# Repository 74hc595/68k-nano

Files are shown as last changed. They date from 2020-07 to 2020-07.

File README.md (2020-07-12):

# 68k nano

A minimal single-board computer based on the venerable ["Texas Cockroach"](https://youtu.be/UaHtGf4aRLs?t=2074)
Motorola 68000 16/32-bit microprocessor.

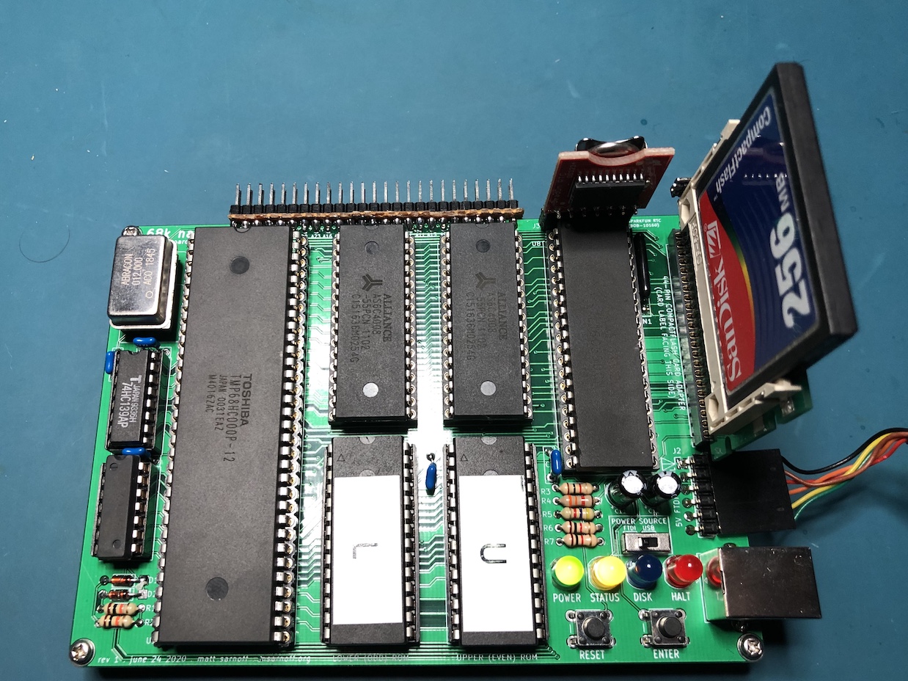
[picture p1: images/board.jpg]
Board image


## Features

- 68HC000 processor running at 12MHz
- 1MB RAM
- 64KB ROM
- 16550 UART providing a 5V FTDI serial port
- 44-pin IDE connector for CompactFlash card adapter
- Connector for SparkFun DS3234 real-time clock
- Only two 74HC glue logic chips required

This might be capable of running uClinux, but I haven't tried it!

## Hardware

The 68k nano hardware is simple and straightforward. It can be built on a
breadboard (though there may be stability issues at higher clock speeds).

### Memory map

Due to the minimal address decoding circuitry, accessing certain memory regions
will cause multiple devices to be selected. This should be avoided.

```
$000000-0xFFFF     ROM (repeats 16 times)
$100000-1FFFFF  X  Forbidden (multiple devices selected)
$200000-2FFFFF     ROM (mirror of $000000-0FFFFF)
$300000-$7FFFF  X  Forbidden (multiple devices selected)
$800000-8FFFFF     Open bus (available for expansion)
$900000-9xxxxF     CompactFlash card
$A00000-AxxxxF     UART
$B00000-BFFFFF  X  Forbidden (multiple devices selected)
$C00000-CFFFFF     RAM
$D00000-DFFFFF  X  Forbidden (multiple devices selected)
$E00000-EFFFFF     RAM (mirror of $C00000-CFFFFF)
$F00000-FFFFFF  X  Forbidden (multiple devices selected)
```

This is summarized with the following equations:

```
/ROMSEL  = /A23
/RAMSEL  =  A22
/UARTSEL =  A23 * /A22 * A21
/CARDSEL =  A20
```

### I/O

The 16550's modem control lines are used as a bit-banged SPI interface. A 7-pin
header is provided for [SparkFun's "DeadOn" DS3234 real-time clock board](https://www.sparkfun.com/products/10160).
Access to SPI is therefore achieved via the 16550's Modem Control Register and Line
Status Register.

A 2mm pitch 44-pin IDE connector is provided for storage devices. This is
intended for CompactFlash card adapters (operating in 16-bit True IDE mode) but
may also work with parallel ATA hard disks. (not tested)

### Interrupts

All interrupt sources are routed through the 16550. All 16550 interrupts invoke
the level 1 autovector (vector offset `$064`) and it is up to the software to
determine the source of the interrupt.

### Building it

`bom.txt` contains a bill of materials. As of this writing (July 2020), all
components are available from major distributors like [Mouser](https://mouser.com)
and [Jameco](https://jameco.com). If purchasing 68000s from eBay, note that [vintage
ICs are a common target of counterfeiters](https://medium.com/supplyframe-hardware/the-underground-parts-store-identifying-counterfeit-computer-chips-3020adbb01f7).
For this project I used [Toshiba TMP68HC000P-12 chips from Jameco](https://www.jameco.com/shop/ProductDisplay?catalogId=10001&langId=-1&storeId=10001&productId=2288039) and
they work just fine.

All parts are through-hole for that extra vintage feel. Note that some of the
decoupling capacitors (C4, C5, C6, C8, and C10) are underneath ICs, so open-frame
IC sockets are required. Large IC sockets can also be expensive (_especially_
DIP-64 sockets!) so a cheaper alternative is to use [breakaway SIP 0.1" machine-pin
headers](https://www.amazon.com/dp/B0187LTEX2/ref=cm_sw_em_r_mt_dp_U_M5IbFbVJ3NVDH).

Due to the spacing of the chips, Textool ZIF sockets won't fit. For the ROMs
U5 and U7, [Aries 28-526-10 low-profile ZIF sockets](https://www.jameco.com/shop/ProductDisplay?catalogId=10001&langId=-1&storeId=10001&productId=102745) will fit,
but _barely_. The release latch may scrape against the RAM IC to its north,
but I've found that it's not a huge deal.

You can use either a full-can or half-can oscillator for X1. Note that if using
an oscillator with a frequency other than 12 MHz, you'll have to update the `F_CPU`
value in the Makefile. (see below) Also note that, if using a 68HC000, the minimum
clock frequency is 4 MHz.

The 44-pin IDE header accepts a CompactFlash adapter board such as [this one](https://www.amazon.com/gp/product/B07Y2MTS13), available from Amazon and other vendors.

## Software

This project uses the [vasm](http://sun.hasenbraten.de/vasm/) assembler and a
standard Makefile. Python 3 and [PySerial](https://pythonhosted.org/pyserial/)
are also required to upload programs to the computer via the serial port. The
Makefile also contains rules for burning ROM images to AT28C256 EEPROMs using
[minipro](https://gitlab.com/DavidGriffith/minipro/) if you have a [TL866II+](https://www.jameco.com/shop/ProductDisplay?catalogId=10001&langId=-1&storeId=10001&productId=2297823)
programmer. (If you don't have a chip programmer, you should get a TL866II+, they
are reasonably priced and available from a number of vendors.)

### Building it

Running `make rom` will build the ROM image and split it into "odd" and "even"
halves, `rom-l.bin` and `rom-u.bin`. Each file should be 32,768 bytes exactly.
Running `make burnrom` will write these files to a pair of AT28C256 EEPROMs
using minipro.

**Note:** if using an oscillator with a frequency other than 12 MHz, change the
value of `F_CPU` appropriately in the Makefile.

The `BAUD` variable in the Makefile sets the baud rate of the serial interface.
Use the included script `baudrate.py` to determine which baud rates are usable
with a given oscillator frequency.

### ROM features

The ROM is fairly minimal--it's closer to a bootloader than an operating system.
It supports loading programs from the root directory of a FAT16-formatted
CompactFlash card and some basic debugging functionality. It also provides a
small set of system calls for I/O to simplify application programs.

The power-up process is as follows:
- Initialize serial port to 57600 baud, 8 data bits, no parity, 1 stop bit.
- Test RAM. If a RAM failure occurs, the failed address is written to the serial
port and the Status LED flashes rapidly. (This is prone to failure when running
on a breadboard at higher clock speeds.)
- Check for the real-time clock module. If found, print the current date and
time to the serial port.
- Check for a CompactFlash card, and attempt to mount the first partition if it
is FAT16-formatted.
- If the "ENTER" pushbutton is NOT held down:
  - If a valid card is inserted, check for a file in the root directory named
    `STARTUP.BIN`. If found, load it into RAM and execute it.
  - If `STARTUP.BIN` was not loaded, enter an interactive command shell.
- If the "ENTER" pushbutton is held down, enter the interactive command shell
  and bypass execution of `STARTUP.BIN`.

Example startup sequence (without `STARTUP.BIN`):
```
68K NANO - ROM VERSION 00009900 (20200708)
(C) 2020 MATT SARNOFF (MSARNOFF.ORG)
TESTING RAM...PASSED

RAM: 1,048,576 BYTES
ROM: 65,536 BYTES
CPU: 12,000,000 HZ
TIME IS 2020-07-07 19:14:36
CARD DETECTED: 250,608 KB 'NO NAME    '
CANNOT LOAD STARTUP.BIN - FILE NOT FOUND

TYPE ? [ENTER] FOR HELP.
>
```

### Command shell

If `STARTUP.BIN` was not loaded, an interactive command shell is available via
the serial port. (57600 baud, 8 data bits, no parity, 1 stop bit). Type `?` and
press Enter for a list of supported commands. They are summarized briefly here.
Note that commands and filenames are _case-insensitive_.

- `.L` - list files in the root directory of the CompactFlash card. Long filenames
  and hidden files are not displayed.
- `.I` - print low-level information about the filesystem on the CompactFlash card.
- `.P file` - print the contents of the file named `file` in the root directory
  of the CompactFlash card as ASCII text.
- `.H file` - print the contenxt of the file named `file` in the root directory
  of the CompactFlash card as a hexdump.
- `.T` - print the current date and time as reported by the real-time clock module.
- `.T YYYYMMDDWWhhmmss` - set the current date and time. The new date/time should
  be expressed as a string of 16 decimal digits with no separators. `WW` should
  be a 2-digit weekday between `01` and `07` inclusive. You can obtain the
  current date/time in this format with the Unix command `date "+%Y%m%d0%u%H%M%S"`.
- `.D` - enter the debugger.
- `file` - any other command is interpreted as a filename to be loaded from the
  root directory of the CompactFlash card and executed. Unlike MS-DOS, the file
  extension _is_ required. e.g. to execute the file named _foo.bin_, enter `FOO.BIN`.
  (`FOO` will attempt to load a file named _foo_ with no extension).

### Serial loader

A break condition on the serial input line enters the serial loader, allowing
programs to be uploaded to RAM from a host computer. The Python script `serload.py`
and the Makefile rules `make load` and `make run` take care of this.

### Debugging

A hardware exception causes a transfer into a basic debugger. The Status LED
flashes rapidly and a register dump is printed to the serial port:

```
*ILLEGAL INSTRUCTION
D0=00000064  D1=0000000A  D2=00000038  D3=00000009
D4=00000000  D5=00000000  D6=00000000  D7=00000000
A0=00E0003C  A1=00001D40  A2=00000000  A3=00F00000
A4=00000000  A5=00000000  A6=000001E2  A7=00EFFFFA
SR=-S0--Z--  PC=00001D3A              USP=7F7EFFDF

[A]BORT/[C]ONTINUE/[S]TEP?
```

Supported commands are:
- `a` - abort execution and return to system.
- `c` - (attempt to) continue execution. (the Trace bit is cleared)
- `s` - set the Trace bit and single-step.

`TRAP #15` is treated as a breakpoint instruction that also enters the debugger.

### API

See `API.md` for a detailed description of the system calls provided by the ROM
API and guidelines for application programs.

## Known issues and shortcomings

- ROM is always present at the bottom of the address space, so the exception
  vectors cannot be overridden by application code.
- Interrupt handling is a hack, since all interrupt sources go through the 16550.
- Address decoding leaves little room for expansion.
- System calls should set the condition codes to simplify application code.

## Future directions

This is a small-scale project. I'm thinking about desiging a larger 68000 board
in the future, so I probably won't continue working on this one. Here are some
project ideas that I won't have time to tackle, but you're welcome to:

- Running an existing 68k monitor like [TUTOR](http://www.easy68k.com/paulrsm/mecb/mecb.htm)
  or [zBug](http://www.kswichit.com/68k/68k.html).
- Running a language like [EhBASIC](https://github.com/jefftranter/68000/tree/master/ehbasic) or a Forth.
- Adding FAT16 write support.
- Booting [uClinux](https://www.bigmessowires.com/2014/11/17/68-katy-68000-linux-on-a-solderless-breadboard/) like Steve Chamberlin did with [68 Katy](https://www.bigmessowires.com/category/68katy/).
- Using the DS3234 real-time clock's SQW output to generate a periodic interrupt.
  (likely necessary for uClinux)

## About

Open hardware, released under the terms of the 3-clause BSD license.

Copyright 2020 Matt Sarnoff.

http://twitter.com/txsector

http://msarnoff.org

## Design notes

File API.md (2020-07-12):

## Application programming

Programs are loaded into RAM starting at the address `APPMEMSTART` (currently
defined as `$E00100`, 256 bytes past the start of RAM). Execution also begins at
this location.

Application programs are executed in supervisor mode. The stack pointer `A7` is
initialized to the end of RAM (`$00F00000`) and registers `D0-D7/A0-A6` are
initialized to `$00000000`.

The interrupt priority level is set to `0`, i.e. interrupts are enabled at
program start.

The UART is enabled and set to 57600 baud, 8 data bits, no parity, 1 stop bit.
The line status interrupt is enabled. A break condition on the serial input
terminates execution of the application and enters the serial loader (see above).

The `TRAP #n` instruction is used to perform system calls. (see below)

### System calls

Application programs can use basic input/output routines in the ROM using the
`TRAP` instruction. (This limits the number of syscalls to 16. Future ROM revisions
may use [A-traps](https://en.wikipedia.org/wiki/Macintosh_Toolbox).)

#### Calling convention

- `D0-D1` - integer arguments.
- `A0-A1` - pointer arguments.
- Additional arguments passed on the stack.
- `D0-D1` - integer return values.
- `A0-A1` - pointer return values.
- `D2-D7/A2-A7/SR` - preserved.
- Registers `D0-D1/A0-A1` not used for return values may have undefined contents
  upon return to the caller. (i.e. the callee may use them as scratch registers)
- The caller is responsible for removing arguments passed on the stack.

The `sys` macro can be used as a wrapper around the `TRAP` instruction.

A common convention for some system calls is to return 0 in `D0` on success, or
a nonzero error code in `D0` on failure. Note that since system calls preserve
condition codes, an explicit `tst d0` is required before branching to an error
handler.

#### `TRAP #0` - `Exit` - return to system

- **Arguments:**
  - none
- **Returns:**
  - none
- **Function:**
  - Terminates the application and returns to the system. This will relaunch
    `STARTUP.BIN` (if present on card) or return to the command shell.

#### `TRAP #1` - `WaitBtn` - wait for button to be pressed

- **Arguments:**
  - none
- **Returns:**
  - none
- **Function:**
  - Pauses execution until the "ENTER" pushbutton on the board is pressed and
    released.

#### `TRAP #2` - `OutChar` - write one character to output device

- **Arguments:**
  - `D0.B` - character to write
- **Returns:**
  - `D0.B` - unmodified
- **Function:**
  - Write one character to the current output device. (The default output device
    is the serial port; see "Input/output customization" below for more info.)
- **Example:**
```
; write a newline character to the output device
        moveq   #$0a,d0
        sys     OutChar
```

#### `TRAP #3` - `OutStr` - write null-terminated string to output device
- **Arguments:**
  - `A0.L` - pointer to null-terminated string
- **Returns:**
  - none
- **Function:**
  - Write a null-terminated string to the current output device.
- **Example:**
```
; write "hello world!" to the output device, followed by a newline
        lea.l   hello,a0
        sys     OutStr
hello:  dc.b    "hello world!\n",0
```

#### `TRAP #4` - `OutFmt` - write formatted string to output device
- **Arguments:**
  - `A0.L` - pointer to null-terminated format string
  - format arguments on stack (caller is responsible for cleanup)
- **Returns:**
  - none
- **Function:**
  - Write a formatted string to the current output device. Format arguments are
    taken from the stack, with the most-recently-pushed quantity treated as the
    first format argument.
  - Unlike C's `printf`, format specifiers are single bytes in the range `$E0-$FF`.
    See `syscalls.inc` for the full list.
  - Since the 68000 stack must always stay word-aligned, byte quantities must
    be pushed on the stack as words.
- **Example:**
```
; writes "567 xyz 89ABCDEF" to the output device, followed by a newline
        move.l  #2309737967,-(sp) ; second argument, printed as 32-bit hex
        move.w  #$237,-(sp)       ; first argument, printed as 16-bit decimal
        lea.l   fmtstr,a0
        sys     OutFmt
        addq    #6,sp
fmtstr: dc.b    FMT_U16," xyz ",FMT_H32,"\n",0
```

#### `TRAP #5` - `InChar` - read one character from input device
- **Arguments:**
  - none
- **Returns:**
  - `D0.B` - received character
- **Function:**
  - Waits for a character to become available from the current input device and
    returns it. (The default input device is the serial port; see "Input/Output
    handlers" below for more info.)
- **Example:**
```
; wait for a character to be typed, then print its hex value surrounded by brackets
        sys     InChar
        move.w  d0,-(sp)
        lea.l   fmtstr,a0
        sys     OutFmt
        addq    #2,sp
fmtstr: dc.b    "[",FMT_H8,"]",0
```

#### `TRAP #6` - `PromptStr` - prompt for string from input device
- **Arguments:**
  - `A0.L` - pointer to destination buffer
  - `D0.L` - maximum allowed length of string
  - `D1.W` - delimiter character and option flags
    - **bits 0-7:** delimiter (terminate prompt when this character is received)
    - **bit 8:** if set, received characters are _not_ echoed to the output device
    - **bit 9:** if set, control characters like Backspace and Ctrl-C are _not_ interpreted
- **Returns:**
  - `A0.L` - unmodified (points to start of string)
  - `(A0)` - user-supplied string with a terminated null byte
  - `D0.L` - number of characters received (excluding null byte)
- **Function:**
  - Prompts for a string from the input device. Returns when the delimiter character
    specified by `D1.B` is received, or (if bit 9 of `D1` is clear) when Ctrl-C (`$03`)
    is received.
  - The string is null-terminated. The buffer pointed to by `A0` should have sufficient
    space for `D0`+1 bytes.
  - If bit 9 of `D1` is clear, the following control characters are interpreted:
    - **Ctrl-C** (`$03`): return immediately with an empty string
    - **Ctrl-H** (`$08`, **DEL** (`$7F`): delete most-recently-entered character
      from the input buffer and (if bit 8 of `D1` is clear) output a backspace
      escape sequence
    - **Ctrl-M** (`CR`, `$0D`): translated to Ctrl-J (`LF`, `$0A`)
- **Example:**
```
; ask for the user's name
        lea.l   name,a0
        moveq   #32,d0    ; max length is 32 bytes (one less than buffer size)
        moveq   #$0a,d1   ; stop when a newline character is received
        sys     PromptStr
; print it
        move.l  a0,-(sp)
        lea.l   fmtstr,a0
        sys     OutFmt
        addq    #4,sp
fmtstr: dc.b    "Hello, ",FMT_S,"!\n",0
name:   dcb.b   33
```

#### `TRAP #7` - `ReadSector` - read one 512-byte sector from the CompactFlash card
- **Arguments:**
  - `D0.L` - sector number (LBA)
  - `D1.L` - number of bytes to read (pass any value >= 512 to load entire sector)
  - `A0.L` - address of destination buffer (must be word-aligned)
- **Returns:**
  - `D0.B` - error code, or 0 if successful
  - `D1.L` - decremented by the number of bytes read
  - `A0.L` - points one byte past the last byte written to the destination buffer
- **Function:**
  - Reads the numbered sector from the CompactFlash card into RAM. An error code
    is returned in `D0` if an error occurs (e.g. no card inserted or invalid sector number)
  - To facilitate reading of multiple sectors into the same buffer, `A0` is advanced
    to point one byte past the last byte written, and `D1` is decremented by the
    actual number of bytes read.
- **Example:**
```
; read the master boot record
        moveq   #0,d0     ; read sector number 0
        moveq   #-1,d1    ; read whole sector
        lea.l   buf,a0
        sys     ReadSector
; print it as a hexdump
        move.l  #512,-(sp) ; number of bytes to dump
        pea     buf        ; start of buffer
        lea.l   fmtstr,a0
        sys     OutFmt
        addq    #8,sp
fmtstr: dc.b    FMT_HEXDUMP,"\n",0
buf:    dcb.b   512
```

#### `TRAP #8` - `ListDirectory` - traverse the root directory of the CompactFlash card
- **Arguments:**
  - `A0.L` - pointer to buffer of at least `DIRBUFSIZE` bytes (must be word-aligned)
  - `D0.L` - should be nonzero on first call; zero on subsequent calls
- **Returns:**
  - `A0.L` - preserved
  - `A1.L` - pointer to 32-byte directory entry within the buffer
  - `D0.W` - status
    - if `D0.W = 0`, there are still entries to iterate over
    - if `D0.W < 0`, iteration is complete
    - if `D0.W > 0`, an error occurred (error code in lower 8 bits)
- **Function:**
  - Iterates over the entries in the root directory of the CompactFlash card.
  - On the first call, the user should pass a nonzero value in `D0`, and should
    set `D0` to zero on subsequent calls.
  - `A0` should be a pointer to a temporary buffer. This can be in a fixed location
    or on the stack. Its contents should not be modified by application code during
    directory traversal.
  - After each call, `A1` points to a 32-byte [FAT16 directory entry](https://en.wikipedia.org/wiki/Design_of_the_FAT_file_system#Directory_entry).
  - Hidden files, deleted files, volume labels, and empty entries are skipped over.
- **Example:**
```
; set up buffer on stack
        link    a6,#-DIRBUFSIZE
        move.l  sp,a0
        moveq   #-1,d0  ; d0 should be nonzero on first call
; loop over entries
.loop:  sys     ListDirectory
        tst.w   d0
        bmi     .done
        bne     .error
        ; do something with the directory entry here
        moveq   #0,d0   ; d0 should be zero on subsequent calls
        bra     .loop
.done:  ; all done
.error: ; handle error
        unlk    a6      ; deallocate temporary buffer
```

#### `TRAP #9` - `FindFile` - look up the named file in the root directory of the CompactFlash card
- **Arguments:**
  - `A0.L` - pointer null-terminated 8.3 filename
  - `A1.L` - pointer to 32-byte buffer where the directory entry will be copied to
- **Returns:**
  - `D0.B` - status code (0 on success, nonzero on error)
  - `A1.L` - preserved
- **Function:**
  - Traverse the root directory until a file with the given name is found.
    Its directory entry is then copied into the 32-byte buffer pointed to by `A1`.
  - The filename should be specified as a DOS-style 8.3 filename (e.g. `FOO.TXT`)
    and is case-insensitive. Long filenames are not considered.
  - Hidden files are ignored. (this is a probably a bug)
- **Example:**
```
; print the size of the file named TEST.TXT
        lea.l   fname,a0
        lea.l   buf,a1
        sys     FindFile
        move.l  FSIZE(a1),-(sp) ; get file size from directory entry
        lea.l   fmtstr,a0
        sys     OutFmt          ; print file size
        addq    #4,sp
fname:  dc.b    "TEST.TXT",0
fmtstr: dc.b    "FILE SIZE: ",FMT_U32," BYTES",0
buf:    dcb.b   32
```

#### `TRAP #10` - `ReadFile` - read the contents of the named file in the root directory of the CompactFlash card into memory
- **Arguments:**
  - `A0.L` - pointer null-terminated 8.3 filename (case-insensitive)
  - `A1.L` - address where the file should be loaded into
  - `D0.L` - maximum number of bytes to load (passing -1 loads entire file)
- **Returns:**
  - `D0.B` - status code (0 on success, nonzero on error)
  - `A0.L` - pointer to beginning of destination memory buffer (orig. value of `A1`)
  - `A1.L` - actual number of bytes loaded
- **Function:**
  - Loads the full contents of the named file into memory.
  - The filename should be specified as a DOS-style 8.3 filename (e.g. `FOO.TXT`)
    and is case-insensitive. Long filenames are not considered.
  - Hidden files are ignored. (this is a probably a bug)
  - Does not return an error if the file is larger than the maximum number of
    bytes specified in `D0`. (this would be a nice enhancement to make it easier
    to detect cases where a file is too big)
- **Example:**
```
; print the first 32K of a file named TEST.TXT
        lea.l   fname,a0
        lea.l   buf,a1
        move.l  #32768,d0
        sys     ReadFile
        move.l  d1,-(sp)  ; number of bytes read
        move.l  a0,-(sp)  ; start of buffer
        lea.l   fmtstr,a0
        sys     OutFmt
        addq    #8,sp
fname:  dc.b    "TEST.TXT",0
fmtstr: dc.b    FMT_BUF,"\n",0
buf:    dcb.b   32768
```

#### `TRAP #11` - `GetDateTime` - read current date and time from the real-time clock
- **Arguments:**
  - none
- **Returns:**
  - `D0.L` - date
    - **bits 31-16:** year (four BCD digits)
    - **bits 15-8:** month (two BCD digits)
    - **bits 7-0:** date (two BCD digits)
  - `D1.L` - weekday and time
    - **bits 26-24:** weekday (one BCD digit)
    - **bits 23-16:** hour (two BCD digits)
    - **bits 15-8:** minute (two BCD digits)
    - **bits 7-0:** second (two BCD digits)
- **Function:**
  - If no real-time clock is present, `D0` and `D1` will both equal 0.
  - If the time is not set (e.g. there has been a power failure), bit 31 of `D0`
    will be set.
- **Example:**
```
; print the date and time
        sys     GetDateTime
        tst.l   d0
        bmi     .time_not_set
        beq     .no_rtc
        lea.l   fmtstr,a0
        movem.l d0-d1,-(sp)
        sys     OutFmt
        addq    #8,sp
fmtstr: dc.b    "DATE IS ",FMT_DATE," AND TIME IS ",FMT_TIME,"\n",0
```

#### `TRAP #12` - `SetDateTime` - set date and time
- **Arguments:**
  - none
- **Returns:**
  - `D0.L` - date
    - **bits 31-16:** year (four BCD digits)
    - **bits 15-8:** month (two BCD digits)
    - **bits 7-0:** date (two BCD digits)
  - `D1.L` - weekday and time
    - **bits 26-24:** weekday (one BCD digit)
    - **bits 23-16:** hour (two BCD digits)
    - **bits 15-8:** minute (two BCD digits)
    - **bits 7-0:** second (two BCD digits)
- **Function:**
  - No validation of the date (bounds-checking fields, ensuring valid BCD) is performed.
- **Example:**
```
; set date and time to Monday, July 6, 2020, 12:34:56
        move.l  #$01123456,d0 ; msb of 01 = Monday
        move.l  #$20200706,d1
        sys     SetDateTime
```

#### `TRAP #13` - `GetSysInfo` - get pointer to system information structure
- **Arguments:**
  - none
- **Returns:**
  - `A0.L` - pointer to system information structure in ROM
    - `0(A0).L` - CPU clock speed in Hz
    - `4(A0).L` - RAM size in bytes
    - `8(A0).L` - ROM size in bytes
    - `12(A0).L` - ROM date
    - `16(A0).W` - ROM major revision
    - `18(A0).W` - ROM minor revision
- **Function:**
  - Allows application code to retrieve system information.

#### `TRAP #14` - reserved

#### `TRAP #15` - `Breakpoint` - enter the debugger
- **Arguments:**
  - none
- **Returns:**
  - none
- **Function:**
  - Prints a register dump and enters the debugger. 

#### Input/output customization

The longword-sized RAM locations `OUTCH_VEC` and `INCH_VEC` contain addressed of
routines used for character output and input. These can be customized to allow
input and output to be redirected.

At boot, the vectors are initialized to routines that write to and read from
the serial port.

`OUTCH_VEC` should contain the address of a function that accepts the byte to
be written in `D0`. It should preserve `A2-A7/D2-D7`.

`INCH_VEC` should contain the address of a function that waits for a byte to
become available and then returns it in `D0`. it should preserve `A2-A7/D2-D7`.

Formatted output using the `OutFmt` system call can also be customized:
- `HEXDIGITS` contains the address of a 16-character string containing the
  character set to use when printing hexadecimal numbers
- `DATE_SEP` contains the byte used as a separator character between components
  when the `FMT_DATE` specifier is used. At boot, it defaults to hyphen `-`.
- `TIME_SEP` contains the byte used as a separator character between components
  when the `FMT_TIME` specifier is used. At boot, it defaults to colon `:`.
- `THOUSANDS_SEP` contains the byte used as a thousands grouping separator when
  printing signed and unsigned decimal values. At boot, it defaults to comma `,`.
  To suppress thousands separators, set it to ASCII NUL. (zero byte)

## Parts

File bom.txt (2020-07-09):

Ref     Part                                            Distributor SKU
----------------------------------------------------------------------------------------------------------
C1-C10  0.1uF decoupling capacitor (ceramic/monolithic)
C11,C12 10uF electrolytic capacitor, 16V+
D1-D2   1N5817 Schottky diode (1N4148 also works)
D3-D6   5mm LED (your choice of color)
J1      USB-B PCB-mount right-angle connector           Jameco 2096245
J2      6-position 0.1" male right-angle header
J3      (optional) 7-position 0.1" header
J4      2x22 2mm header
JP1     3-position 0.1" male straight header + jumper
R1,R2   10k resistor, 1/4W
R3      1k resistor, 1/4W
R4-R7   Resistors for LEDs D3-D6 (330/1k)
RN1     10k bussed resistor network (SIP-7)
SW1,SW2 6mm tactile switch
U1      74HC139 dual 2-to-4 line decoder (DIP-16)
U2      74HC14 hex inverting Schmitt trigger (DIP-14)
U3      68000 microprocessor (DIP-64)                   Jameco 2288039
U4,U6   AS6C4008-55PCN 512Kx8 static RAM (DIP-32)       Jameco 242448           Mouser 913-AS6C4008-55PCN
U5,U7   AT28C256 32Kx8 EEPROM (DIP-28)                  Jameco 74843            Mouser 556-AT28C25615PU
U8      TL16C550 UART (DIP-40)                          Jameco 288809
X1      5V oscillator (DIP-8 or DIP-14)

Optional peripherals
--------------------
Low profile ZIF-28 sockets for U5/U7 - Jameco 102745 (Aries 28-526-10)
SparkFun DeadOn RTC Breakout - https://www.sparkfun.com/products/10160
CompactFlash to 2.5" 44-pin IDE adapter - https://www.amazon.com/gp/product/B07Y2MTS13

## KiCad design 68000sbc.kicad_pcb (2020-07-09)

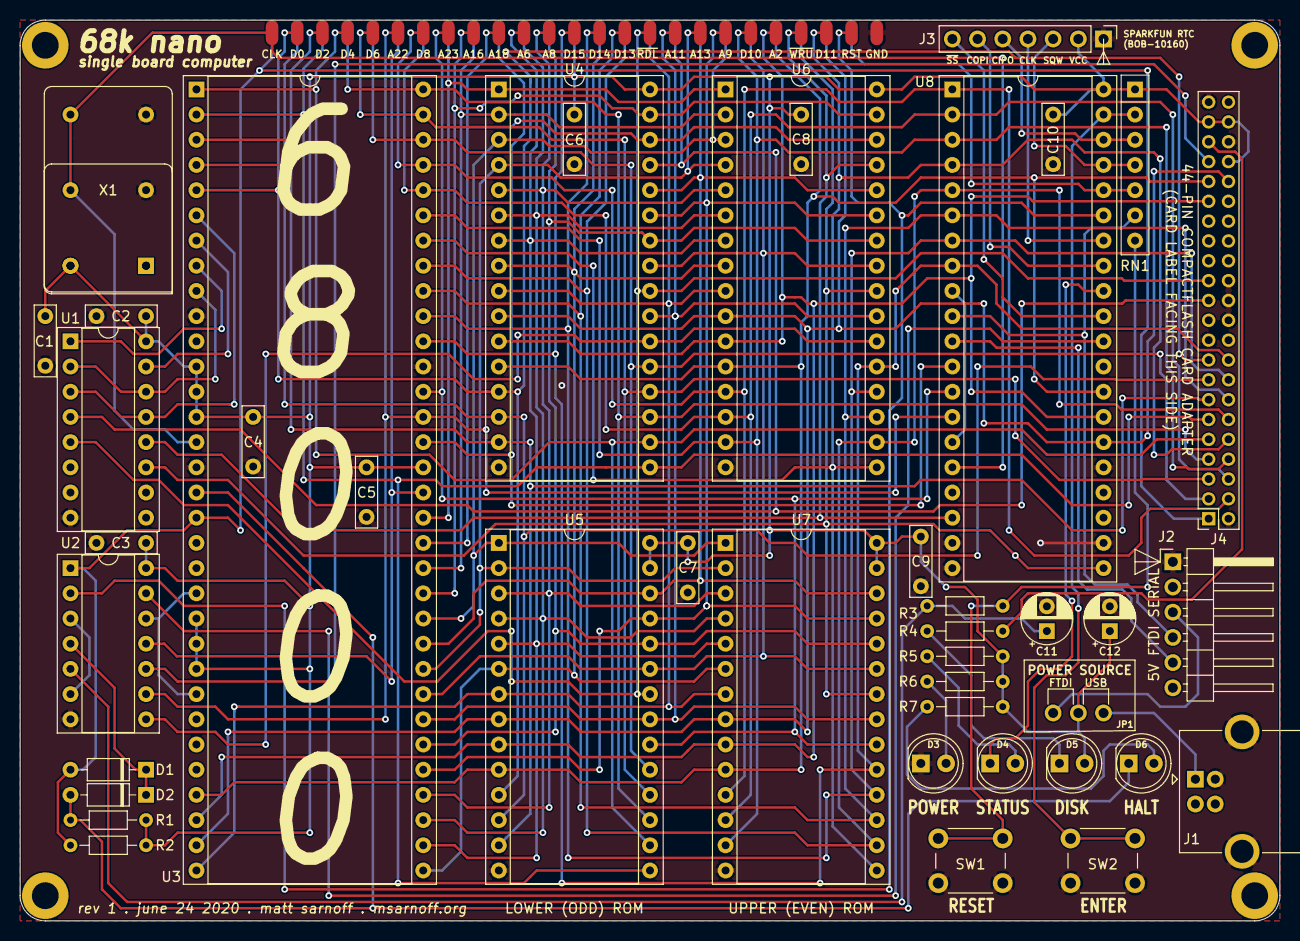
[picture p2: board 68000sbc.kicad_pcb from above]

Board: 2 copper layers, 127.0 x 90.8 mm, 45 parts (1 on the bottom side), 80 nets.

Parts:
C1, C2, C3, C4, C5, C6, C7, C8, C9, C10: 0.1uF; C_Rect_L7.0mm_W2.0mm_P5.00mm
C11, C12: 10uF; CP_Radial_D5.0mm_P2.50mm
D1, D2: 1N5817; D_DO-35_SOD27_P7.62mm_Horizontal
D3: POWER; LED_D5.0mm
D4: LED; LED_D5.0mm
D5: CARD; LED_D5.0mm
D6: HALT; LED_D5.0mm
J1: USB_B; USB_B_OST_USB-B1HSxx_Horizontal
J2: 5V FTDI SERIAL; PinHeader_1x06_P2.54mm_Horizontal
J3: RTC (SparkFun BOB-10160); PinHeader_1x07_P2.54mm_Vertical
J4: CFCARD/IDE; PinHeader_2x22_P2.00mm_Vertical
J5: EXPANSION (F.Cu); PadRow_1x25_P2.54mm
J6: EXPANSION (B.Cu); PadRow_1x25_P2.54mm
JP1: POWER SELECT; PinHeader_1x03_P2.54mm_Vertical
R1, R2: 10k; R_Axial_DIN0204_L3.6mm_D1.6mm_P7.62mm_Horizontal
R3: 1k; R_Axial_DIN0204_L3.6mm_D1.6mm_P7.62mm_Horizontal
R4, R5, R6, R7: 1k*; R_Axial_DIN0204_L3.6mm_D1.6mm_P7.62mm_Horizontal
RN1: 10k; R_Array_SIP7
SW1: RESET; SW_PUSH_6mm
SW2: BTN1; SW_PUSH_6mm
U1: 74HC139; DIP-16_W7.62mm_Socket
U2: 74HC14; DIP-14_W7.62mm_Socket
U3: TMP68HC000P-12; DIP-64_W22.86mm_Socket
U4, U6: AS6C4008-55PCN; DIP-32_W15.24mm_Socket
U5, U7: 28C256; DIP-28_W15.24mm_Socket
U8: TL16C550; DIP-40_W15.24mm_Socket
X1: 12MHz; Oscillator_DIP-14
X2: 12MHz; Oscillator_DIP-8

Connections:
/A1: J4.35, J6.21, U3.29, U4.12, U5.10, U6.12, U7.10, U8.28
/A2: J4.33, J5.21, U3.30, U4.11, U5.9, U6.11, U7.9, U8.27
/A3: J4.36, J6.23, U3.31, U4.10, U5.8, U6.10, U7.8, U8.26
/A4: J6.16, U3.32, U4.9, U5.7, U6.9, U7.7
/A5: J6.14, U3.33, U4.8, U5.6, U6.8, U7.6
/A6: J5.11, U3.34, U4.7, U5.5, U6.7, U7.5
/A7: J6.11, U3.35, U4.6, U5.4, U6.6, U7.4
/A8: J5.12, U3.36, U4.5, U5.3, U6.5, U7.3
/A9: J5.19, U3.37, U4.27, U5.25, U6.27, U7.25
/A10: J6.12, U3.38, U4.26, U5.24, U6.26, U7.24
/A11: J5.17, U3.39, U4.23, U5.21, U6.23, U7.21
/A12: J6.20, U3.40, U4.25, U5.23, U6.25, U7.23
/A13: J5.18, U3.41, U4.4, U5.2, U6.4, U7.2
/A14: J6.18, U3.42, U4.28, U5.26, U6.28, U7.26
/A15: J6.19, U3.43, U4.3, U5.1, U6.3, U7.1
/A16: J5.9, U3.44, U4.31, U6.31
/A17: J6.9, U3.45, U4.2, U6.2
/A18: J5.10, U3.46, U4.30, U6.30
/A19: J6.8, U3.47, U4.1, U6.1
/A20: J6.6, U2.11, U3.48
/A21: J6.10, U3.50, U8.12
/A22: J5.6, U2.9, U3.51, U8.14
/A23: J5.8, U3.52, U5.20, U7.20, U8.13
/CPUCLK: J5.1, U3.15, U8.16, X1.8, X2.5
/D0: J4.17, J5.2, U3.5, U4.13, U5.11
/D1: J4.15, J6.2, U3.4, U4.14, U5.12
/D2: J4.13, J5.3, U3.3, U4.15, U5.13
/D3: J4.11, J6.3, U3.2, U4.17, U5.15
/D4: J4.9, J5.4, U3.1, U4.18, U5.16
/D5: J4.7, J6.4, U3.64, U4.19, U5.17
/D6: J4.5, J5.5, U3.63, U4.20, U5.18
/D7: J4.3, J6.5, U3.62, U4.21, U5.19
/D8: J4.4, J5.7, U3.61, U6.13, U7.11, U8.1
/D9: J4.6, J6.7, U3.60, U6.14, U7.12, U8.2
/D10: J4.8, J5.20, U3.59, U6.15, U7.13, U8.3
/D11: J4.10, J5.23, U3.58, U6.17, U7.15, U8.4
/D12: J4.12, J6.15, U3.57, U6.18, U7.16, U8.5
/D13: J4.14, J5.15, U3.56, U6.19, U7.17, U8.6
/D14: J4.16, J5.14, U3.55, U6.20, U7.18, U8.7
/D15: J4.18, J5.13, U3.54, U6.21, U7.19, U8.8
/EXTIRQ: J6.24, RN1.5, U8.36
/IRQ: U2.13, U8.30
/R,~W: U1.2, U1.14, U3.9
/RESET: J5.24, U2.2, U8.35
/RTC_CIPO: J3.5, RN1.3, U8.38
/RTC_CLK: J3.4, U8.34
/RTC_COPI: J3.6, U8.33
/RTC_SQW: J3.3, RN1.4, U8.37
/RXD: J2.5, U8.11
/TXD: J2.4, RN1.6, U8.10
/~A20: J4.37, U2.10
/~A22: U2.8, U4.22, U6.22
/~AS: U1.3, U1.13, U3.6
/~BTN1: RN1.2, SW2.2, U8.39
/~CFLED: J4.39, R4.1
/~HALT: D2.2, D6.1, R1.2, U3.17
/~IRQ: U2.12, U3.21, U3.25
/~LDS: U1.1, U3.8
/~RDL: J4.25, J5.16, U1.5, U4.24, U5.22
/~RDU: J6.22, U1.11, U6.24, U7.22, U8.21
/~RESET: D1.2, J4.1, J6.1, R2.2, U2.1, U3.18
/~RESETBTN: R3.2, RN1.7, SW1.2
/~RTC_SS: J3.7, U8.31
/~UDS: U1.15, U3.7
/~WRL: J4.23, J6.17, U1.4, U4.29
/~WRU: J5.22, U1.12, U6.29, U8.18
GND: C1.2, C2.2, C3.2, C4.2, C5.2, C6.2, C7.2, C8.2, C9.2, C10.2, C11.2, C12.2, D3.1, J1.4, J1.5, J2.1, J3.1, J4.2, J4.19, J4.22, J4.24, J4.26, J4.30, J4.40, J4.43, J5.25, J6.25, SW1.1, SW2.1, U1.8, U2.7, U3.10, U3.16, U3.53, U4.16, U5.14, U6.16, U7.14, U8.19, U8.20, U8.22, U8.25, X1.7, X2.4
unnamed: C11.1, R3.1, U2.5
unnamed: D1.1, D2.1, U2.4
unnamed: D3.2, R6.1
unnamed: D4.1, U8.32
unnamed: D4.2, R5.2
unnamed: D5.1, R4.2
unnamed: D6.2, R7.1
unnamed: J1.1, JP1.3
unnamed: J2.3, JP1.1
unnamed: U2.3, U2.6
unnamed: U8.9, U8.15
unnamed: X1.1, X2.1
VCC: C1.1, C2.1, C3.1, C4.1, C5.1, C6.1, C7.1, C8.1, C9.1, C10.1, C12.1, D5.2, J3.2, J4.38, J4.41, J4.42, J6.13, JP1.2, R1.1, R2.1, R5.1, R6.2, R7.2, RN1.1, U1.16, U2.14, U3.12, U3.13, U3.14, U3.22, U3.23, U3.24, U3.49, U4.32, U5.27, U5.28, U6.32, U7.27, U7.28, U8.40, X1.14, X2.8

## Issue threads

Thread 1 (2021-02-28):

this device can run mac os 7?

ojej, 2021-02-28:
Normal native system and program. Of course rom is not free but users can put rom if have.

Normal old mac with LCD screen, good keyboard and usb mouse (and sound) sound good, very good.

rickyzhang82, 2021-06-04:
In theory, you could. But there is still a lot of work to support peripherals

- hard drive/sony floppy
- frame buffer video output
- ...

You need to hack Mac ROM to support your bespoke peripherals. Have you checked out the work in Basilisk II ROM patching? That's a major work to write a hardware/emulated hardware driver in ROM patching.

ojej, 2021-06-05:
I, unfortunately, can't do that.
So this is just a suggestion for you.

thanks

rickyzhang82, 2021-06-06:
I bought the parts plus a 5v tolerant Xilinx CPLD for glue logic. I'm going to replicate this design and add a VGA video card based on [the idea from Burr Smith.](https://aresluna.org/attached/computerhistory/articles/macintoshbytepreview/systemarchitecture)

In 80s, Macintosh team designed their frame buffer DMA in PAL (see diagram below). I may use CPLD to get this done. This would be a fun project.

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

mifritscher, 2021-12-22:
Hint: You have already bit-hang SPI at the UART. For SPI there are many displays available ;)
Not the fasted method, but should be enough for a simple start.

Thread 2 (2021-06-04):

Request more info on CF card read

rickyzhang82, 2021-06-04:
Thanks for sharing your design. I read your ROM in CF card parts. Do you have a document on CF card/IDE protocol timing and interface protocol?

I saw `/CFIRQ` in J4 doesn't connect to anywhere. Does CF card require interrupt to read a sector?

TIA.

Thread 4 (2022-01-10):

Garbage on D9

GBeushausen, 2022-01-10:
I've built the board, but the terminal emulator is not responding. After further inspection with an oscilloscope i see that there is garbage on D9. It also stays if i remove the chips except the CPU. The rest seems normal. I've tried multiple CPUs. Any idea what i could do to finde the cause of this issue?

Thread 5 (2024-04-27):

Nano++

danboid, 2024-04-27:
This is one of the most interesting homebrew computers I've ever seen, very cool project! I found it via the Fuzix web site.

If you can design a better one of these that has video output and a couple of joystick ports I'd definitely want to build one.

Have you considered the possibility of using software defined video output like on the Uzebox or the rbox?

https://uzebox.org/

https://rossumblog.com/2010/06/10/rbox-a-diy-32-bit-game-console-for-the-price-of-a-latte/

74hc595, 2024-04-27:
I started working one about 3 years ago and got pretty far before putting it on hold. I can’t promise it’ll ever be finished, I might publish my work in progress design someday…

Check out my Amethyst project for an example of software defined video. Very similar hardware as the Uzebox but generates color using composite artifacting instead of an expensive encoder chip.

danboid, 2024-04-27:
I hope you do fnd the time to do another 68K based computer.

There is now the Uzebox Omega which doesn't require the decoder chip:

https://uzebox.org/wiki/Omega

Thanks

Closed 2024-04-27.

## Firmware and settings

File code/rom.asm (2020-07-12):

; vim:noet:sw=8:ts=8:sts=8:ai:syn=asm68k

        include "68000sbc.inc"

ROM_VER_MAJ     equ     $0000
ROM_VER_MIN     equ     $9910
ROM_DATE_YEAR   equ     $2020
ROM_DATE_MONTH  equ     $07
ROM_DATE_DAY    equ     $11

BAUD_DIV        equ     (((F_CPU*10)/(16*BAUD))+5)/10 ; compute one extra decimal place and round
BAUD_DIV_L      equ     (BAUD_DIV&$FF)
BAUD_DIV_U      equ     ((BAUD_DIV>>8)&$FF)

        org     ROM
                dc.l    INITIAL_SP
                dc.l    RESET
                dc.l    VEC_BUSFAULT
                dc.l    VEC_ADRERROR
                dc.l    VEC_ILLINSTR
                dc.l    VEC_DIVBY0
                dc.l    VEC_CHK
                dc.l    VEC_TRAPV
                dc.l    VEC_PRIVVIOL
                dc.l    VEC_TRACE
                dc.l    VEC_LINE1010
                dc.l    VEC_LINE1111
                dc.l    VEC_RESERVED    ;12
                dc.l    VEC_RESERVED    ;13
                dc.l    VEC_RESERVED    ;14
                dc.l    VEC_UNINIVEC
        rept    8
                dc.l    VEC_RESERVED    ;16-23
        endr
                dc.l    VEC_SPURIOUS
                dc.l    VEC_AUTOVEC1
                dc.l    VEC_AUTOVEC2
                dc.l    VEC_AUTOVEC3
                dc.l    VEC_AUTOVEC4
                dc.l    VEC_AUTOVEC5
                dc.l    VEC_AUTOVEC6
                dc.l    VEC_AUTOVEC7
        ; System calls (TRAP #n)
                dc.l    SYS_Exit                ; 0  - return to system
                dc.l    SYS_WaitBtn             ; 1  - wait for button press and release
                dc.l    SYS_OutChar             ; 2  - single character output
                dc.l    SYS_OutStr              ; 3  - string output
                dc.l    SYS_OutFmt              ; 4  - formatted string output
                dc.l    SYS_InChar              ; 5  - single character input
                dc.l    SYS_PromptStr           ; 6  - prompt for string from input device
                dc.l    SYS_ReadSector          ; 7  - read sector from CF card
                dc.l    SYS_ListDirectory       ; 8  - iterate through directory
                dc.l    SYS_FindFile            ; 9  - find named file in directory
                dc.l    SYS_ReadFile            ; 10 - read file from CF card into memory
                dc.l    SYS_GetDateTime         ; 11 - read time and date from real-time clock
                dc.l    SYS_SetDateTime         ; 12 - set real-time clock time and date
                dc.l    SYS_GetSysInfo          ; 13 - return pointer to system info structure
                dc.l    $FFFFFFFF               ; 14 - reserved
                dc.l    VEC_BREAKPT             ; 15 - break into debugger/monitor
;-------------------------------------------------------------------------------
RESET:
        ; uart init
                lea.l   UART,a1
                move.b  #%00001101,FCR(a1)      ; enable FIFO
                move.b  #%10000011,LCR(a1)      ; 8 data bits, no parity, 1 stop bit, DLAB=1
                move.b  #BAUD_DIV_L,DLL(a1)     ; set divisor latch low byte
                move.b  #BAUD_DIV_U,DLM(a1)     ; set divisor latch high byte
                bclr.b  #7,LCR(a1)              ; disable divisor latch
                clr.b   SCR(a1)                 ; clear the scratch register
                move.b  #(1<<MCR_COPI),MCR(a1)  ; SPI COPI idles low
        ; read the button state at launch
                move.b  MSR(a1),SCR(a1)         ; save the button state into the scratch register
; Welcome message
                led_on
                lea.l   str_startup,a0
                bl      _printstr
                move.l  rom_version,d0
                bl      _printhexl
                moveq   #' ',d0
                tx_char d0,a1
                moveq   #'(',d0
                tx_char d0,a1
                move.l  rom_date,d0
                bl      _printhexl
                lea.l   str_credits,a0
                bl      _printstr
;-------------------------------------------------------------------------------
; Power-on self-test
;-------------------------------------------------------------------------------
                lea.l   str_ramtest,a0  ;print startup message
                bl      _printstr
; test RAM
; unrolled for a bit more speed
        ; write test pattern
                lea.l   RAM,a0          ; start address
                lea.l   RAMEND,a3       ; end address
                move.l  #$A5C99C5A,d0   ; test word 1
                move.l  d0,d1
                not.l   d1              ; test word 2
.1:
        rept 8
                move.l  d0,(a0)+
                move.l  d1,(a0)+
        endr
                cmp.l   a0,a3
                bne     .1
        ; read back
                lea.l   RAM,a0          ; start address
                lea.l   RAMEND,a3       ; end address
.2:
        rept 8
                cmp.l   (a0)+,d0        ; read back longword and compare
                bne     testfail
                cmp.l   (a0)+,d1
                bne     testfail
        endr
                cmp.l   a0,a3
                bne     .2
testpass:
                lea.l   str_testpass,a0
                bl      _printstr
                bra     ready
testfail:
                lea.l   -4(a0),a2       ; back up to address of failure fail
                lea.l   str_testfail,a0 ; print message
                bl      _printstr
                move.l  a2,d0
                bl      _printhexl
; flash LED to indicate failure
lockup:         led_tgl
                move.l  #$8000,d0
.1:             dbra    d0,.1
                bra     lockup
;-------------------------------------------------------------------------------
str_startup:    asciz   "\n\n68K NANO - ROM VERSION "
str_credits:    asciz   ")\n(C) 2020 MATT SARNOFF (MSARNOFF.ORG)\n"
str_ramtest:    asciz   "TESTING RAM..."
str_testpass:   asciz   "PASSED\n"
str_testfail:   asciz   "FAILED AT "
                even
;-------------------------------------------------------------------------------
; print d0 as 8 hex digits to serial port with base address a1
; clobbers d1 and d2
; does not use the stack, suitable for use without RAM
_printhexl:     moveq   #7,d1
.loop:          rol.l   #4,d0           ; nibble to lower 4 bits
                move.w  d0,d2
                and.w   #%1111,d2       ; isolate nibble
                move.b  (hexdigits,pc,d2),d2    ; lookup character
                tx_wait a1              ; print digit
                move.b  d2,THR(a1)
                dbra    d1,.loop
                rl
hexdigits:      dc.b    "0123456789ABCDEF"
;-------------------------------------------------------------------------------
; print null-terminated string in a0 to serial port with base address a1
; clobbers d0
; does not use the stack, suitable for use without RAM
_printstr:      move.b  (a0)+,d0        ; get byte
                beq     .2              ; found the null?
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

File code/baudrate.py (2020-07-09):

#!/usr/bin/env python3

# Baud rate calculator for 16550 UART

import sys

BASE_FREQ = 12_000_000 if len(sys.argv) < 2 else float(sys.argv[1])
#BASE_FREQ = 12_587_500
PERCENT_ERROR_THRESHOLD = 3.0

STANDARD_RATES = [
        230400,
        115200,
        57600,
        38400,
        28800,
        19200,
        14400,
        9600,
        7200,
        4800,
        3600,
        2400,
        1800,
        1200
]

def percent_error(actual, expected):
    return abs((actual-expected)/expected)*100

print(f'Baud rate divisors for base frequency of {BASE_FREQ/1_000_000:.6f} MHz:')
for rate in STANDARD_RATES:
    divisor = BASE_FREQ/(16*rate)
    divisor_rounded = round(divisor)
    actual = BASE_FREQ/divisor_rounded/16
    pct_err = percent_error(actual, rate)
    label = '✅' if pct_err <= PERCENT_ERROR_THRESHOLD else '❌'
    print(f'{label} {rate:6} baud: divisor={divisor_rounded:<5} (actual={actual:.3f} baud, error={pct_err:.2f}%)')

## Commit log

2020-07-09 initial import
    [68000sbc.kicad_pcb, 68000sbc.sch]
2020-07-12 rom 0009910
    - holding button at reset skips startup.bin
    - PromptStr better handling of DEL/CR
    - add some missing newlines
    [rom.asm]
